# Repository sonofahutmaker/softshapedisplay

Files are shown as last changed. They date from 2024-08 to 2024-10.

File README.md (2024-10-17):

# SILICONE DREAM
The complexity of meshing physical design requirements with data-driven logic has long been the focus and vexation of artists and engineers wanting to build kinetic sculptural and data display artifacts. Traditional shape displays require high complexity, as previous models require a one to one ratio between actuator number and data resolution. We present SILICONE DREAM, an open-source system for building soft shape display devices which can convey trends about continuous data as well as function in artistic installations. SILICONE DREAM utilizes a silicone top layer over a grid of actuator controlled shafts in order to interpolate between data values without added design complexity. SILICONE DREAM functions as a kinetic sculptural object which can be positioned either horizontally or vertically and has been designed for live collaboration with performing artists and as a self-contained system for generating changing 3D shapes. Because the SILICONE DREAM system is modular, it can easily expand to incorporate other forms of media such as screen-based visuals and generative audio. SILICONE DREAM is controlled by an embedded system with custom software, and contributes a generalizable system for future shape display design for both artistic and scientific use cases.

https://github.com/user-attachments/assets/e616f878-cf12-4654-9811-e8060be1162c

The first SILICONE DREAM soft shape display device replicating changing generated terrain (example application wave-terrain-synth-visual).

https://github.com/user-attachments/assets/90aeedf5-37ed-43ab-a104-1c8a341bd6bf

The first SILICONE DREAM soft shape display device responding to music in real time.

## Software Setup Guide
This setup guide relates only to the software side of building a shape display. Please follow the [Instructables link](https://www.instructables.com/SILICONE-DREAM-Soft-Shape-Display-Device/) for building directions for the hardware portion of the shape display. The software libraries can be used with different shape display hardware setups, including changing number of actuators, so the hardware can be changed to better fit your use cases.

### **1. On Raspberry Pi, clone repo:**

<code>git clone https://github.com/sonofahutmaker/softshapedisplay.git</code>

### **2. Install requirements:**

<code>cd softshapedisplay</code>

<code>pip install -r requirements.txt</code>

### **3. Connect data source:**

The soft shape display system receives data over OSC. The first time you run the application, you must include the IP address of the Raspberry Pi device you are running the app on and the port number to receive data on. The device must be connected to the same Wifi network as the device sending data. See Example Apps section for details on sending data to your application from another source.

Run <code>python main.py --help</code> for details on all command line arguments.

The first time you run the app, you must also include the number of servo motors being used. The example build uses 16.

<code>python main.py -ip RASPI_IP_ADDRESS_HERE --port RECEIVING_PORT_HERE -n NUMBER_SERVOS_HERE</code>

### **4. Customize settings:**

The first time you run main.py a config file, config.ini, will be generated with preset values. You can change these settings through command line arguments or directly in config.ini.

Important settings include 

    - data_range: which is the full possible range of incoming data
    - servo_type: standard or continuous. Standard is recommended and enable by default, but continuous is supported if this argument is set.
    - angle_range: if using a standard servo, what is the full angle range it can turn to. Switch high and low values if the servo is installed upside down.
    - shaft_len, traversal_time, forward_throttle, backward_throttle, zero_throttle, speed only need to be set if using continuous rotation servos.

The full list of command line arguments is as follows:
```
  -h, --help            show this help message and exit
  -ip IP                ip address of device this is running on to receive
                        data
  -p PORT, --port PORT  port number to receive OSC messages on
  -n NUM_SERVOS, --num_servos NUM_SERVOS
  -d DATA_RANGE [DATA_RANGE ...], --data_range DATA_RANGE [DATA_RANGE ...]
                        possible range of data values low to high like '0.0
                        1.0'
  -a ANGLE_RANGE [ANGLE_RANGE ...], --angle_range ANGLE_RANGE [ANGLE_RANGE ...]
                        for standard servo, angle range low to high like '180
                        0' with order dependent on orientation
  -s {standard,cont}, --servo_type {standard,cont}
  --shaft_len SHAFT_LEN
                        for cont. rot servos, length of pusher shaft in mm
  -t TRAVERSAL_TIME, --traversal_time TRAVERSAL_TIME
                        for cont. rot servos, time in secs to move shaft all
                        the way up at full throttle
  -f FORWARD_THROTTLE, --forward_throttle FORWARD_THROTTLE
                        for cont. rot servos, direction and full power value
                        for moving shafts up
  -b BACKWARD_THROTTLE, --backward_throttle BACKWARD_THROTTLE
                        for cont. rot servos, direction and full power value
                        for moving shafts down
  -z ZERO_THROTTLE, --zero_throttle ZERO_THROTTLE
                        for cont. rot. servos, throttle value that stops servo
                        spinning
  --speed SPEED         for cont. rot. servos, multiplier for throttle
```

### **5. Run Application and Receive Data:**

Run the application with <code>python main.py</code>. Add any settings needed to this command as shown above. Once the application is running, it can recieve data over OSC from another source at the IP address and port configured. 

OSC Messages should be sent with either address <code>/block</code> or <code>/list</code>

Servo number is determined by which position it is attached to on the servo hat on the Raspberry Pi.

OSC Message formats which can be received:

To change the data value (and corresponding position) of a single servo:
```
/block SERVO_NUM DATA_VAL
```
i.e.
```
/block 3 0.5
```
will set the (0 indexed) servo of index 3 to the position corresponding to the data value of 0.5. If the set data range is 0 to 1, this means the servo will push its shaft to halfway up.

To change the data values (and corresponding positions) of all servos:
```
/list DATA_VAL DATA_VAL DATA_VAL DATA_VAL ...
```
with data values for all servos.

i.e. if you have set the servo number to be 4, a message of
```
/list 0.0 0.2 0.5 1.0
```
will set the 0th servo to the position corresponding to the data value of 0.0, the 1st to 0.2, the 2nd to 0.5, and the last to 1.0

## Example Apps -- slidersui.maxpat and wave-terrain-synth-visual.maxpat
Both example applications are Max Patchers (Max application can be downloaded [here](https://cycling74.com/products/max)) which send data over OSC to a running soft shape display application. There are built in OSC libraries for many programming languages, including Python, and applications, so these example applications by no means cover all the ways data can be sent to a soft shape display device.

They both make use of the <code>/list</code> message address to send data values to a shape display with 16 servos. You can look at and edit these patchers even without an active Max license, and use them to test, just not save changes.

### **1. First look at the slidersui.maxpat:**
It has 16 sliders, which correspond to the levels of the 16 servos, with a data range between 0.0 and 1.0. This is a great tester application to make sure you are able to receive data over OSC and that your servos are behaving as expected.

When a slider or sliders change, a message is generated in the /list message format like <code>/list 0. 0. 0. 0. 0. 0. 0. 0. 0. 0. 0. 0. 0. 0. 0. 0.</code>. 

This message is sent as soon as it is generated to the (example) IP address 192.168.86.37 and port number 1338. This happens in the the object with <code>udpsend 192.168.86.37 1338</code>. Change the IP address and port number to that of your Raspberry Pi, making sure the Raspberry Pi and the device running the Max Patch are on the same Wifi. Make sure you have set the data range in your soft shape display application to 0.0 - 1.0. Move each slider and verify that you are receiving data and that your device's servos are moving as expected.

### **2. wave-terrain-synth-visual.maxpat:**
This patcher also generates a list of values to be sent to all 16 servos and sends them using the same <code>udpsend 192.168.86.37 1338</code> message. But this patcher generates the values using a wave terrain synthesis algorithm. After enabling your microphone (options > audio status > power button), the audio input is used to generate a changing terrain which is visualized. This terrain is then downsampled to 16 points across its surface, and these values are sent to the Raspberry Pi every 60ms, turning the surface of the shape display into the same terrain as the generated output. This application can also produce audio from exploring the surface of the terrain. This example application demonstrates one way an algorithm can be used to continually change the surface of a soft shape display device.

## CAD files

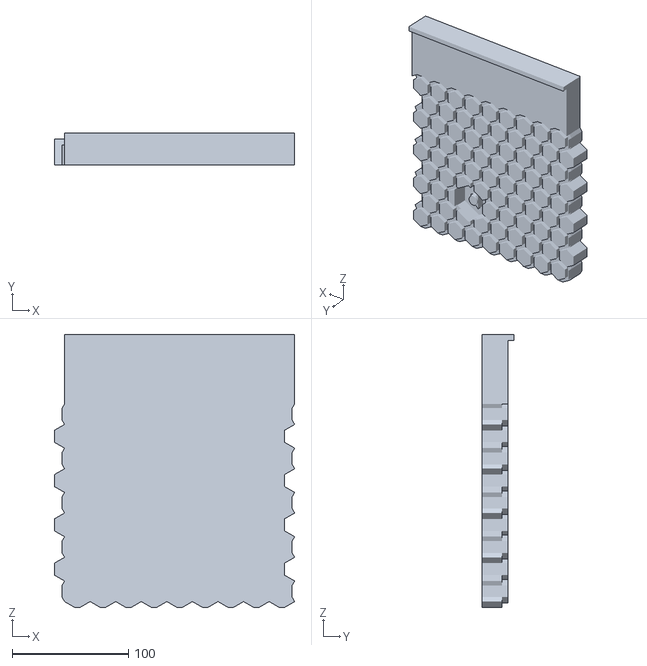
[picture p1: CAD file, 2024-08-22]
build_files/30INCH_TOP_MOLD_FOR_PRINT/0_1.stl
206.8 x 27.3 x 234.8

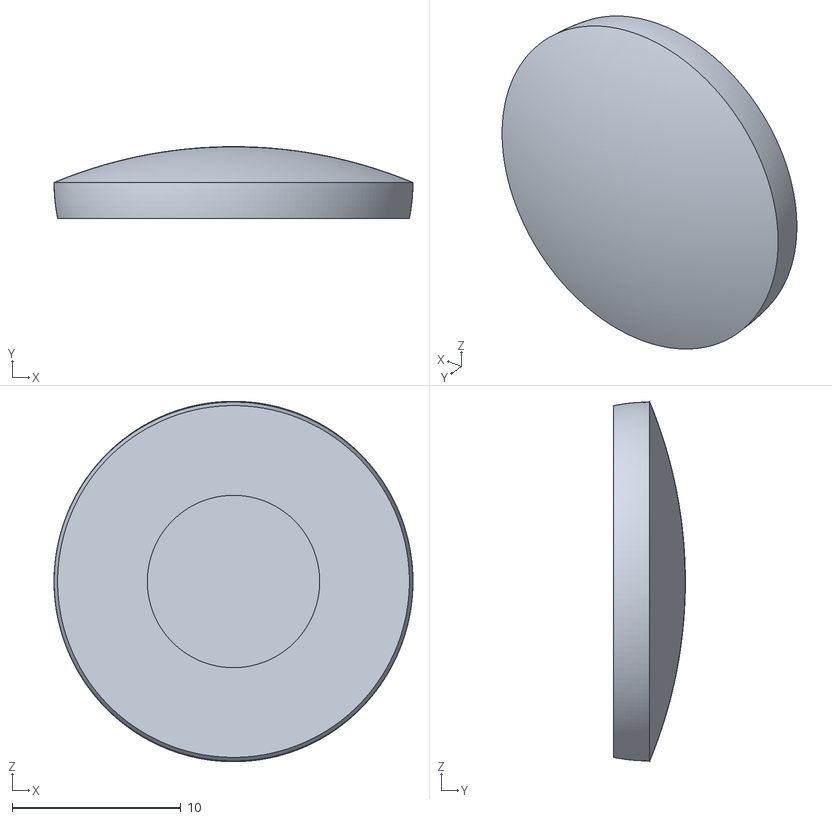
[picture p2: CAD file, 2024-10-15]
build_files/MOLD_CAP.stl
21.2 x 4.25 x 21.3

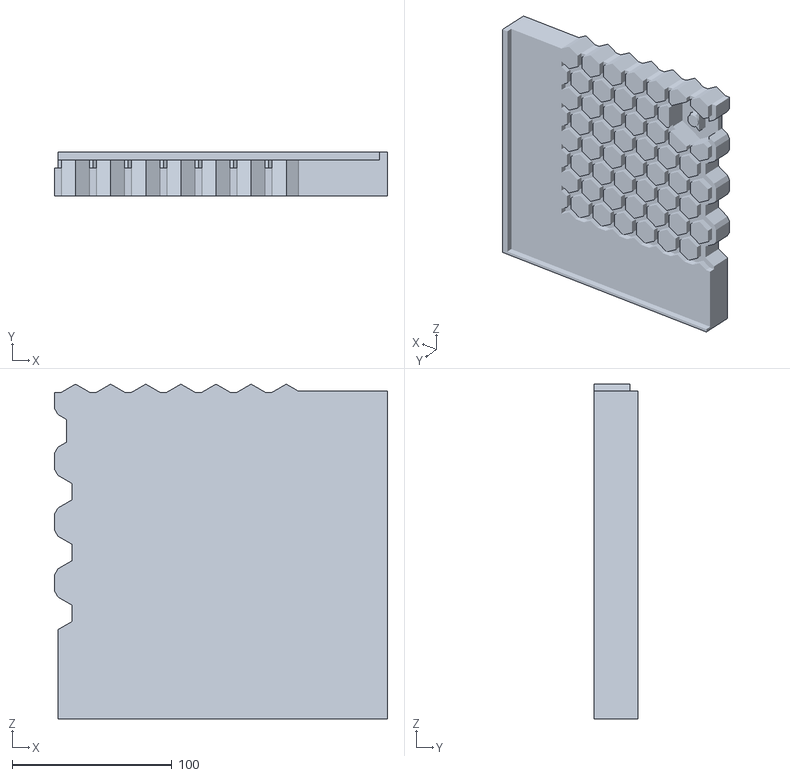
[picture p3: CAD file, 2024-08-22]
build_files/30INCH_TOP_MOLD_FOR_PRINT/3_3.stl
208.5 x 27.3 x 209.6

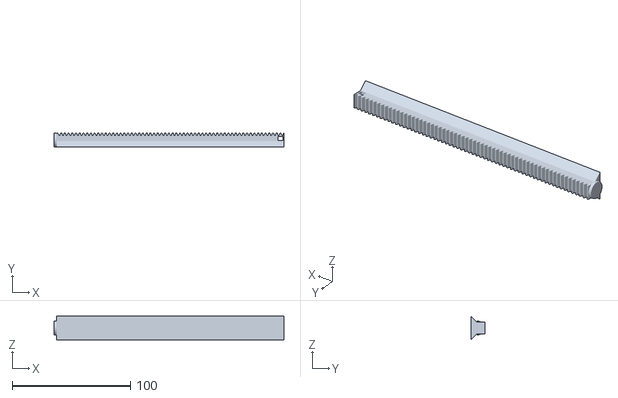
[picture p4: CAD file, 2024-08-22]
build_files/6_INCH_SHAFT.stl
194.4 x 12.0 x 20.0

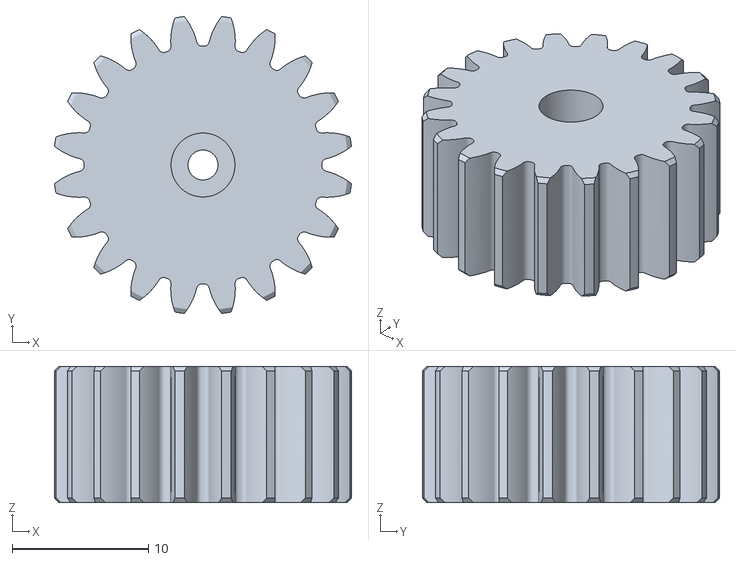
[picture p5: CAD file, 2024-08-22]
build_files/20_MM_GEAR.stl
21.8 x 21.8 x 10.0

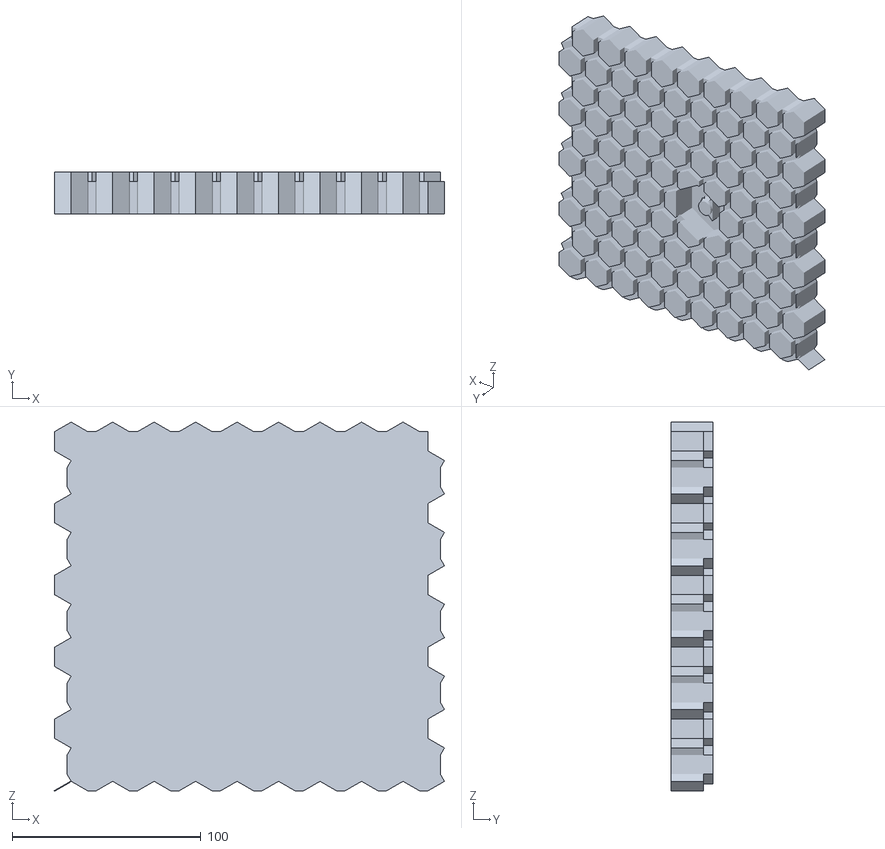
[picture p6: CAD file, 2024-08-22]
build_files/30INCH_TOP_MOLD_FOR_PRINT/1_2.stl
206.8 x 22.2 x 195.6

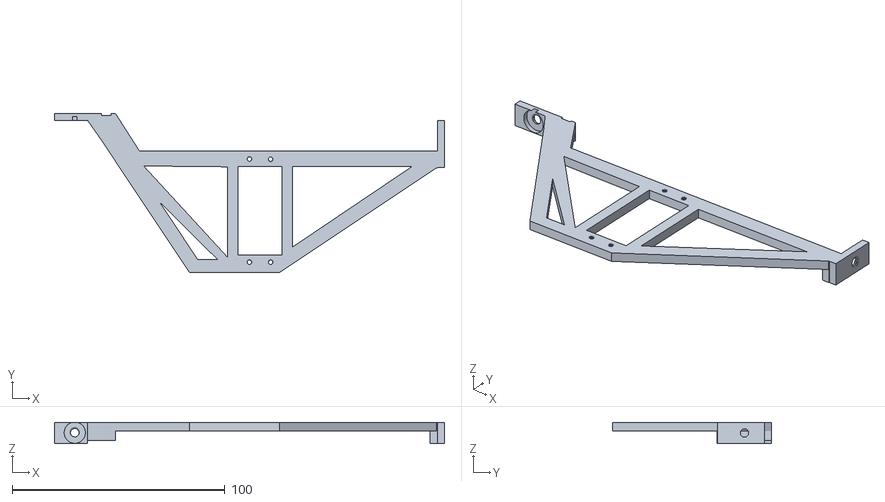
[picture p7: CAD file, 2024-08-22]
build_files/STANDARD_SERVO_HOLDER_BACK_ROW.stl
183.4 x 74.8 x 10.1

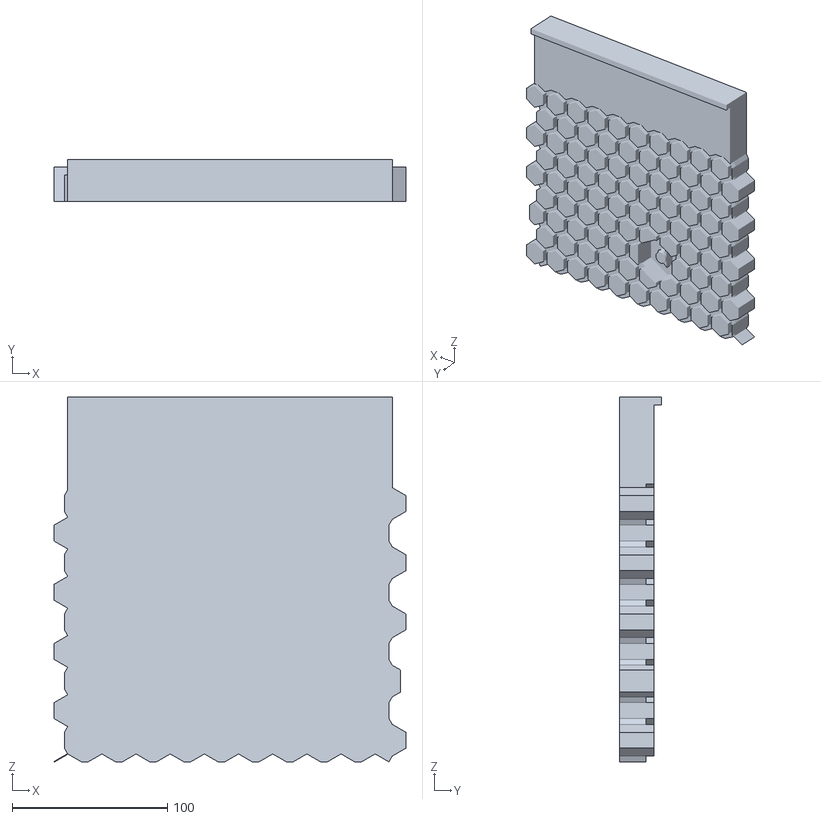
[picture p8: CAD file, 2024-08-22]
build_files/30INCH_TOP_MOLD_FOR_PRINT/0_2.stl
226.6 x 27.3 x 234.8

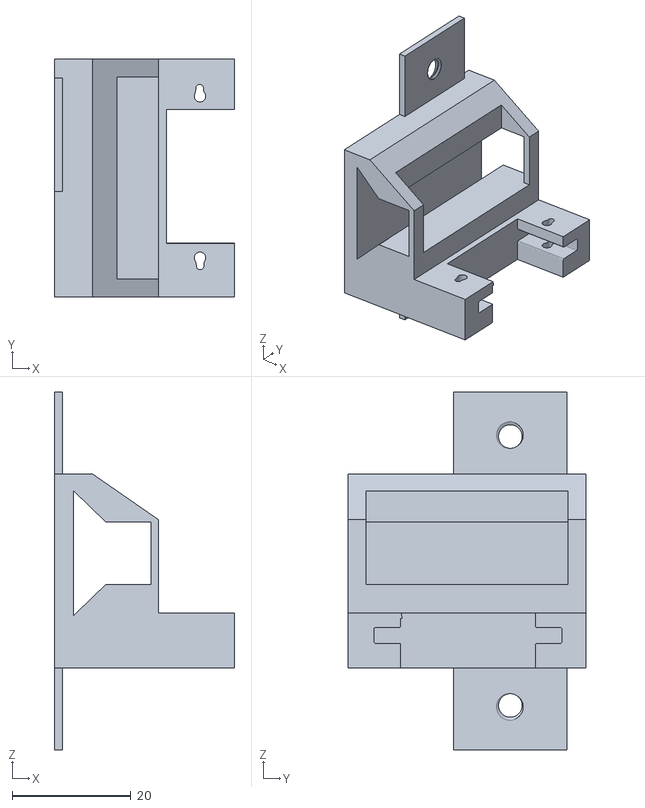
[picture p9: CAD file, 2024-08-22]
build_files/MICRO_SERVO_AND_SHAFT_HOLDER.stl
30.4 x 40.0 x 60.3

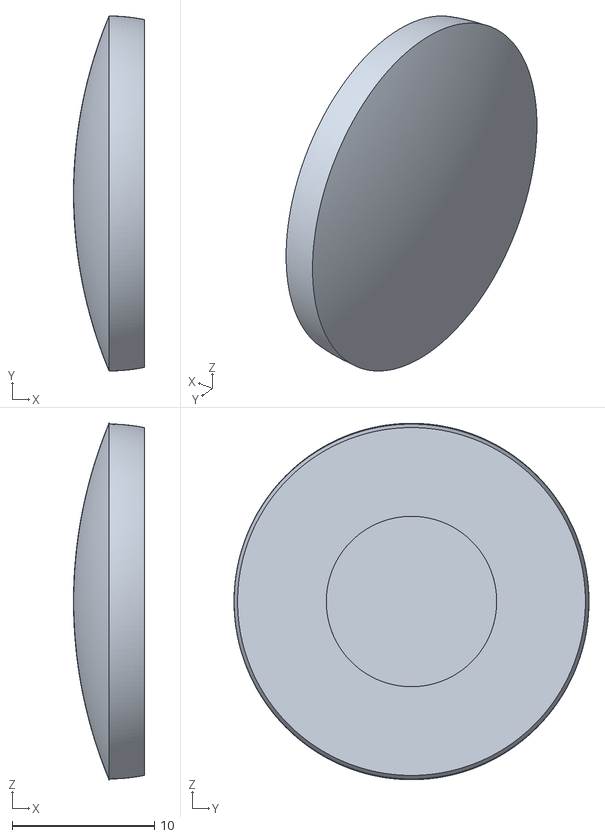
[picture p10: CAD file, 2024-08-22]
build_files/SHAFT_CAP.stl
5.00 x 25.0 x 25.1

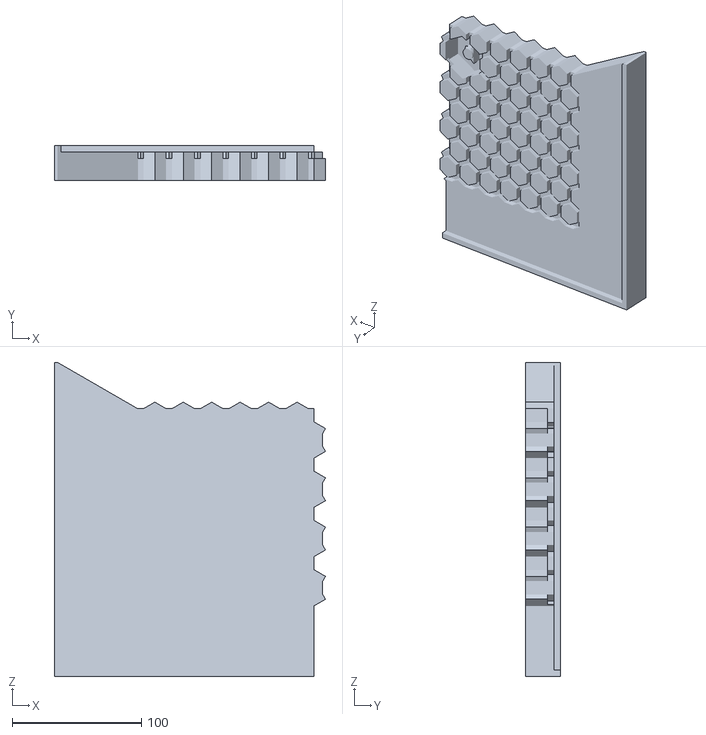
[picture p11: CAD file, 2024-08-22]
build_files/30INCH_TOP_MOLD_FOR_PRINT/3_0.stl
209.5 x 27.3 x 242.8

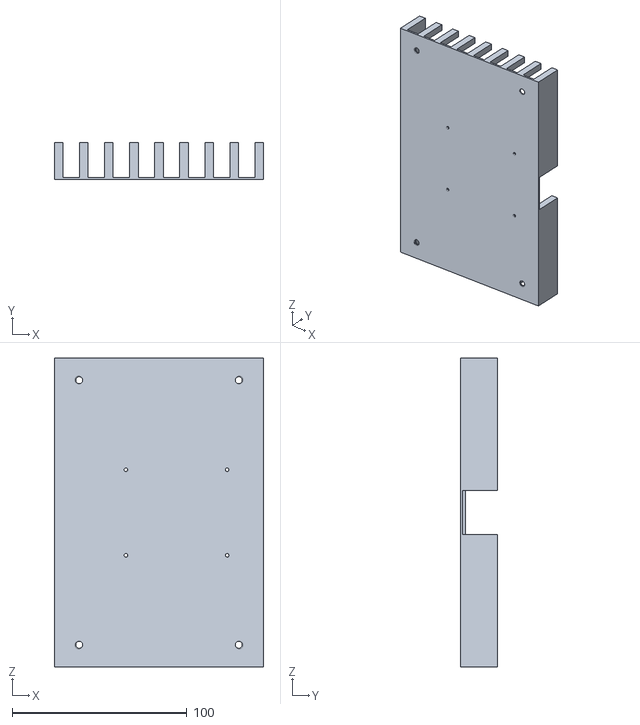
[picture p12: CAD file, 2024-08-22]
build_files/RASPI_HOUSING.stl
120.0 x 21.3 x 177.0

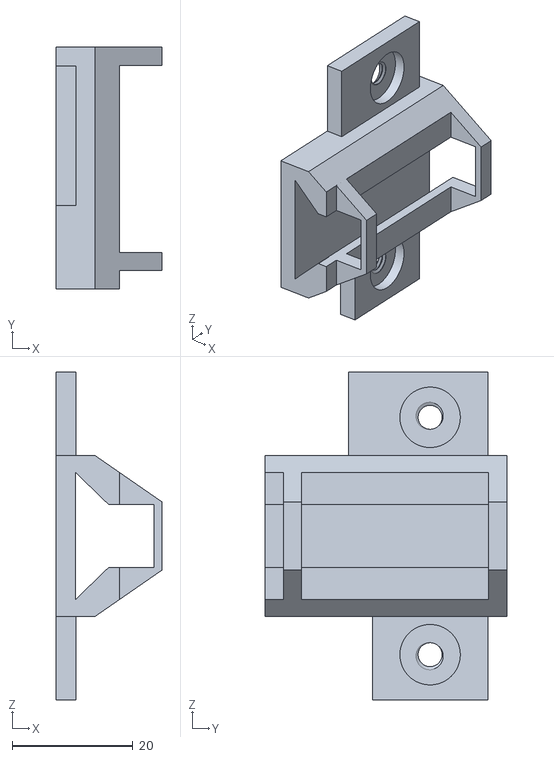
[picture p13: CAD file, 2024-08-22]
build_files/SHAFT_HOLDER.stl
17.6 x 40.0 x 54.3

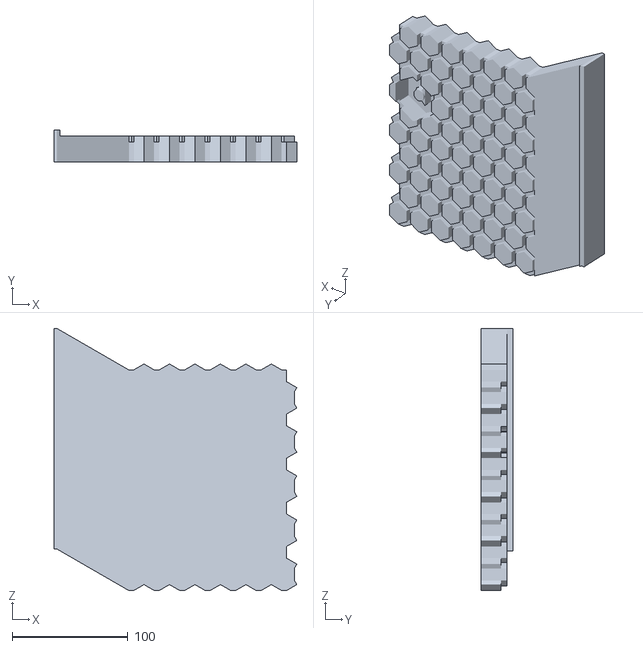
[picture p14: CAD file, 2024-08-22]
build_files/30INCH_TOP_MOLD_FOR_PRINT/2_0.stl
209.5 x 27.3 x 226.2

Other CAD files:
build_files/30INCH_TOP_MOLD_FOR_PRINT/2_2.stl
build_files/30INCH_TOP_MOLD_FOR_PRINT/0_0.stl
build_files/30INCH_TOP_MOLD_FOR_PRINT/3_2.stl
build_files/FOOT_CAP.stl
build_files/20_MM_GEAR.f3d
build_files/30INCH_TOP_MOLD_FOR_PRINT/0_3.stl
build_files/30INCH_TOP_MOLD_FOR_PRINT/1_0.stl
build_files/30INCH_TOP_MOLD_FOR_PRINT/1_1.stl
build_files/30INCH_TOP_MOLD_FOR_PRINT/1_3.stl
build_files/30INCH_TOP_MOLD_FOR_PRINT/2_1.stl
build_files/30INCH_TOP_MOLD_FOR_PRINT/2_3.stl
build_files/30INCH_TOP_MOLD_FOR_PRINT/3_1.stl
build_files/6_INCH_SHAFT.f3z
build_files/CORNER_CAP.f3d
build_files/CORNER_CAP.stl
build_files/FOOT_CAP.f3d
build_files/STANDARD_SERVO_HOLDER.stl

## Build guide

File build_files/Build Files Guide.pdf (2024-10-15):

STANDARD_SERVO_ASSEMBLY.f3z contains Fusion models of
- STANDARD_SERVO_HOLDER.stl
- SHAFT_HOLDER.stl
- 120_MM_GEAR.stl
And shows how a standard servo and pusher shaft are attached to the frame between two top bars

STANDARD_SERVO_ASSEMBLY_BACK_ROW.f3z contains Fusion models of
- STANARD_SERVO_HOLDER_BACK_ROW.stl
- SHAFT_HOLDER.stl
- 120_MM_GEAR.stl
And shows how a standard servo and pusher shaft are attached to the frame between one top bar and one side bar (as occurs for one row of design)

MICRO_SERVO_ASSEMBLY.f3z contains Fusion model of
- MICRO_SERVO_AND_SHAFT_HOLDER.stl
- 20_MM_GEAR.stl
And shows how a micro (continuous rotation) servo and pusher shaft are attached to the top bars of the frame

6_INCH_SHAFT.f3z contains Fusion models of
- 6_INCH_SHAFT.stl: 6” shaft is actually length 6” + length of shaft holder so at full extension the shaft can extend 6” past the top of the shaft holder
- SHAFT_CAP.stl: 6” shaft press fits into the cap, and should be secured with super glue

RASPI_HOUSING.f3z contains a Fusion model of
- RASPI_HOUSING.stl: housing with holes for RaspberryPi to screw into, and for the housing to attach to the bottom of the frame. Slots provide places to channel wires from servos to the Raspi and affix with zip ties

MOTOR_FRAME_ASSEMBLY.f3z
Shows the assembly of frame pieces with attached standard servo holders and shaft holders. Can be used for reference measurements when assembling. Micro servo and shaft holders can similarly be attached at the same measurements on the top bars as the shaft holders shown in this file

FOOT_CAP.f3d contains a Fusion model of
- FOOT_CAP.stl: a protective cap for the feet of the frame so they don’t scratch the surface it rests on. Can be printed in TPU to be less likely to scratch.

CORNER_CAP.f3d contains a Fusion model of
- CORNER_CAP.stl: a protective cap for the sharp corners of the frame. Will need to be adjusted depending on how tight your tolerances are for the physical build with the silicone top

120MM_GEAR.f3z contains a Fusion model of
- 120_MM_GEAR.stl: larger gear for standard servo assembly. Can be modified to incorporate servo horns.

20_MM_GEAR.f3d contains a Fusion model of
- 20_MM_GEAR.stl: smaller gear for continuous rotation servo assembly

30INCH_TOP_MOLD_WITH_LIP.f3z contains Fusion models of silicone top layer and
- 30INCH_TOP_MOLD_FOR_PRINT (folder): all the pieces of the silicone mold, broken up to fit into a Bambu 3D printer. Must be assembled, glued, and made watertight before silicone can be poured

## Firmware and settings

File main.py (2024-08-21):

from ShapeDisplayManager import ShapeDisplayManager
from OSCManager import OSCManager
import asyncio
import argparse
from os.path import exists
from utils import *

def check_ini():
    return exists("config.ini")

# command line arguments for running app
def parse_my_args():
    parser = argparse.ArgumentParser()
    parser.add_argument("-ip", required=not check_ini(),
                        help="ip address of device this is running on to receive data")
    parser.add_argument("-p", "--port", required=not check_ini(),
                        help="port number to receive OSC messages on")
    parser.add_argument("-n", "--num_servos", required=not check_ini())
    parser.add_argument("-d", "--data_range", nargs='+', 
                        help="possible range of data values low to high like '0.0 1.0'")
    parser.add_argument("-a", "--angle_range", nargs='+',
                        help = "for standard servo, angle range low to high like '180 0' \
                            with order dependent on orientation")
    parser.add_argument("-s", "--servo_type", choices=["standard", "cont"])

    # CONSTANTS FOR CONT ROTATION SERVOS
    # length of pusher shaft in mm, not including length of servo holder
    parser.add_argument("--shaft_len", help="for cont. rot servos, length of pusher shaft in mm") 
    parser.add_argument("-t", "--traversal_time",  
                        help="for cont. rot servos, time in secs to move \
                        shaft all the way up at full throttle")
    parser.add_argument("-f", "--forward_throttle",  
                        help="for cont. rot servos, direction and \
                            full power value for moving shafts up") # full positive throttle value
    parser.add_argument("-b", "--backward_throttle",
                        help="for cont. rot servos, direction and \
                            full power value for moving shafts down") # full negative throttle value
    parser.add_argument("-z", "--zero_throttle", 
                        help="for cont. rot. servos, throttle \
                            value that stops servo spinning")
    parser.add_argument("--speed", help="for cont. rot. servos, multiplier for throttle")

    args = parser.parse_args()
    return args

async def loop():
    while True:
        await asyncio.sleep(0)

async def main():
    args = parse_my_args()
    generate_ini(args)
    servo_type = retrieve_config('servo_type')
    displayManager = ShapeDisplayManager(int(retrieve_config('num_servos')), servo_type)
    await displayManager.zeroAllServos()
    oscManager = OSCManager(displayManager)
    transport, protocol = await oscManager.init_osc()

    await loop()

    transport.close()

asyncio.run(main())

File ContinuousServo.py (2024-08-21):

from Servo import Servo
from utils import *
import asyncio

# class instantiated when using continuous rotation servos
# it's recommended to use standard servo to avoid 
# tuning difficulties with cont. rot over time
# this class is available in case your use case 
# requires cont. rotation servos for increased torque, etc
class ContinuousServo(Servo):
    def __init__(self):
        super().__init__()
        self.shaft_len = float(retrieve_config('shaft_len'))
        self.traversal_time = float(retrieve_config('traversal_time'))
        self.forward_throttle = float(retrieve_config('forward_throttle'))
        self.zero_throttle  = float(retrieve_config('zero_throttle'))
        self.backward_throttle = float(retrieve_config('backward_throttle'))
        self.speed = float(retrieve_config('speed'))
        self.zero_val = self.dataValueToShaftHeight(0)
    
    # convert data value to shaft top position in mm
    # middle of data range == 0mm
    def dataValueToShaftHeight(self, val):
        SHAFT_BOTTOM_POS = -self.shaft_len/2
        SHAFT_TOP_POS = self.shaft_len/2
        newPos = (val - self.data_low) * (SHAFT_TOP_POS - SHAFT_BOTTOM_POS) / (
            self.data_high - self.data_low
        ) + SHAFT_BOTTOM_POS
        return newPos
    
    def getDistanceToTravel(self, currPosition, nextPosition):
        return nextPosition - currPosition
    
    # based on recorded time that the servos take to move a shaft to max extension
    def getTimeToPosition(self, distance):
        # may have to be adjusted to account for variable force on shaft as silicone stretches
        travelTime = self.traversal_time * (abs(distance)/self.shaft_len) * self.speed
        return travelTime
    
    def getThrottle(self, distance):
        if distance < 0: # traveling down
            return self.backward_throttle * self.speed
        elif distance > 0: #travling up
            return self.forward_throttle * self.speed
        # if position is the same as before
        return self.zero_throttle
    
    # move servo until fully extended, then move back to zero position
    # if servos become misaligned over time, can increase time to go to 
    # full extension to make sure they are all at same height before zeroing
    async def zeroServo(self, servoNum, servoKit):
        print("zeroing servonum ", servoNum)
        print("setting servo " , servoNum, "to throttle ", self.forward_throttle * self.speed)
        servoKit.continuous_servo[servoNum].throttle = self.forward_throttle * self.speed
        await asyncio.sleep(self.traversal_time * self.speed)
        servoKit.continuous_servo[servoNum].throttle = self.backward_throttle * self.speed
        print("setting servo ", servoNum, "to throttle ", self.backward_throttle * self.speed)
        await asyncio.sleep((self.traversal_time * self.speed)/2)
        print("stopping servo ", servoNum)
        servoKit.continuous_servo[servoNum].throttle = self.zero_throttle

    # set servo to correct throttle for the time necessary
    # to move to new position
    async def moveServo(self, servoNum, positions, servoKit, data_val, shapeManager):
        oldPos = positions[servoNum]
        newPos = self.dataValueToShaftHeight(data_val)
        dist = self.getDistanceToTravel(oldPos, newPos)
        timeTaken = self.getTimeToPosition(dist)
        throttle = self.getThrottle(dist)
        servoKit.continuous_servo[servoNum].throttle = throttle
        print("moveServo setting servo ", servoNum," throttle to ", throttle)
        await asyncio.sleep(timeTaken)
        print("after ", timeTaken, "seconds, stopping servo ", servoNum)
        servoKit.continuous_servo[servoNum].throttle = self.zero_throttle
        shapeManager.updatePositionGrid(servoNum, newPos)

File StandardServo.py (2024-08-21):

from Servo import Servo
from utils import *

# class instantiated when using standard rotational servos
class StandardServo(Servo):
    def __init__(self):
        super().__init__()
        # pulling config values for angle range
        self.lowest_angle = float(retrieve_config('low', 'angle_range'))
        self.highest_angle = float(retrieve_config('high', 'angle_range'))
        self.zero_angle = (max(self.lowest_angle, self.highest_angle) - 
                           min(self.lowest_angle, self.highest_angle))/2
        self.zero_val = self.zero_angle
        
    async def zeroServo(self, servoNum, servoKit):
        print("zeroing servonum ", servoNum)
        servoKit.servo[servoNum].angle = self.zero_angle
    
    # update one servo to appropriate angle for data val
    async def moveServo(self, servoNum, positions, servoKit, data_val, shapeManager):
        newAngle = self.dataValueToAngle(data_val)
        print("moving servo ", servoNum, "to ", newAngle)
        servoKit.servo[servoNum].angle = newAngle
        shapeManager.updatePositionGrid(servoNum, newAngle)

    # converting data value to angle servo needs to be set to
    def dataValueToAngle(self, val):
        angle = (val - self.data_low) * (self.highest_angle - self.lowest_angle) / (
            self.data_high - self.data_low
        ) + self.lowest_angle
        return angle

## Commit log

2024-02-29 controlling one servo with data
2024-05-04 refactoring for non-continous rotation servos. Has been tested on the pi and servos are moving as expected
2024-06-02 starting to add LED logic
2024-06-02 iterating on led control
2024-06-04 adjustment since LED orientation has flipped
    [main.py]
2024-08-15 commenting out LED functions for 1.0 release
2024-08-15 removing LED functionality for 1.0 release
2024-08-15 trying to get LEDs working
2024-08-16 starting to seperate utilities functions into servo classes and finishing config file setup
2024-08-19 finishing refactor to use command line arguments to generate config file and easily switch between standard and continuous rotation servos
2024-08-21 clarifying comment about zero_val of servos
2024-08-22 adding build fusion and stl files for print and assembly
    [0_0.stl, 0_1.stl, 0_2.stl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]
2024-10-15 Adding example apps with data flow from Max patches
2024-10-17 turning on metro button
